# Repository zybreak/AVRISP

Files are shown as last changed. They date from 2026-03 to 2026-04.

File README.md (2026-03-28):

AVR ISP Shield for Arduino
===========================
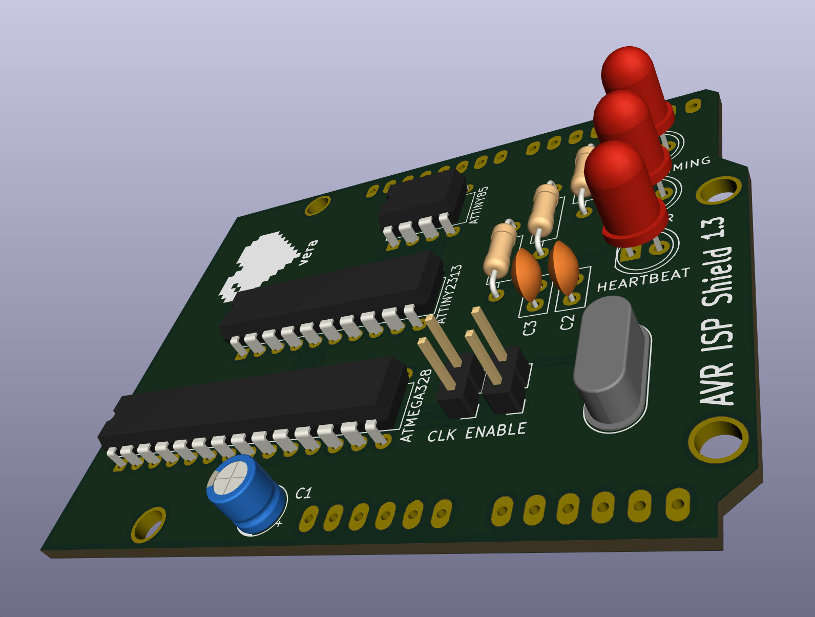
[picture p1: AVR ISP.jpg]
AVR ISP Shield of Arduino


This is an AVR ISP Shield for Arduino

Repository Contents
-------------------
* **/Hardware** - Kicad PCB .pro .sch and .brb files and PDF of Schematic
* **/Software** - Arduino Sketch for Using the Board

Version History
---------------
* V0.1 Functions well for the ATTiny85 but seem to be having problems with the ATMega328 - working on it!
* V1.0 Fully working - has a rearrange from previous versions which avoids grounding on the USB connector on an Uno.
* V1.3 Board update
   - Updated the LED pins to match the ones used in the arduino as isp sketch.
   - Added reset capacitor to prevent the arduino from resetting before programming.
   - Added support for an external clock.

License Information
-------------------
The hardware is released under [Creative Commons Share-alike 3.0](http://creativecommons.org/licenses/by-sa/3.0/).  
All other code is open source so please feel free to do anything you want with it; you buy me a beer if you use this and we meet someday ([Beerware license](http://en.wikipedia.org/wiki/Beerware)).
Also this boiler plate is yoinked from Sparkfun with thanks.

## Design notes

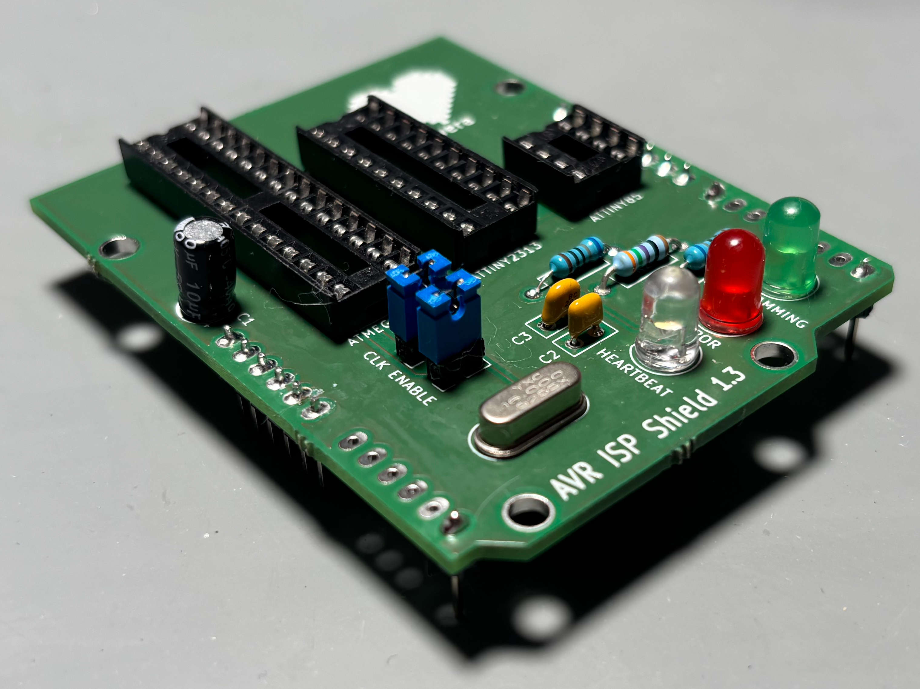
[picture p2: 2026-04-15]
AVR ISP Built.jpg

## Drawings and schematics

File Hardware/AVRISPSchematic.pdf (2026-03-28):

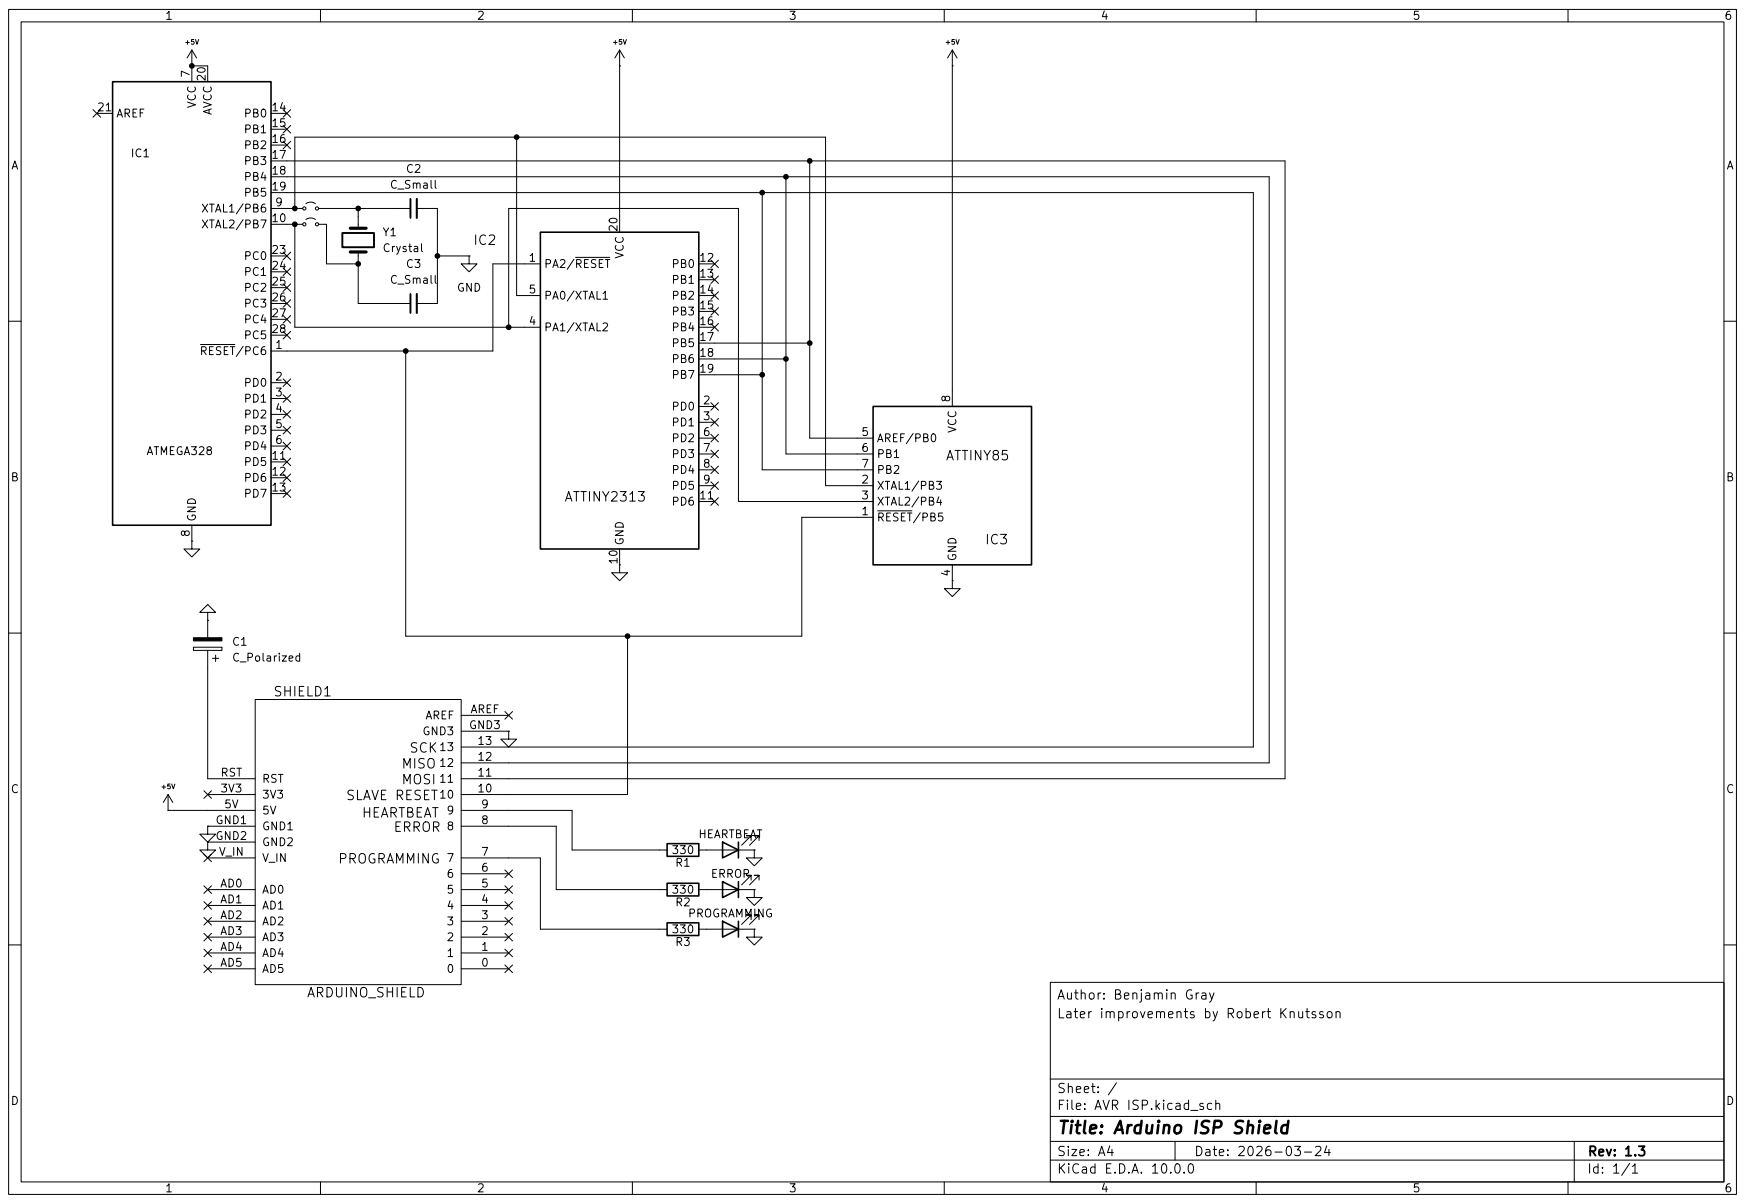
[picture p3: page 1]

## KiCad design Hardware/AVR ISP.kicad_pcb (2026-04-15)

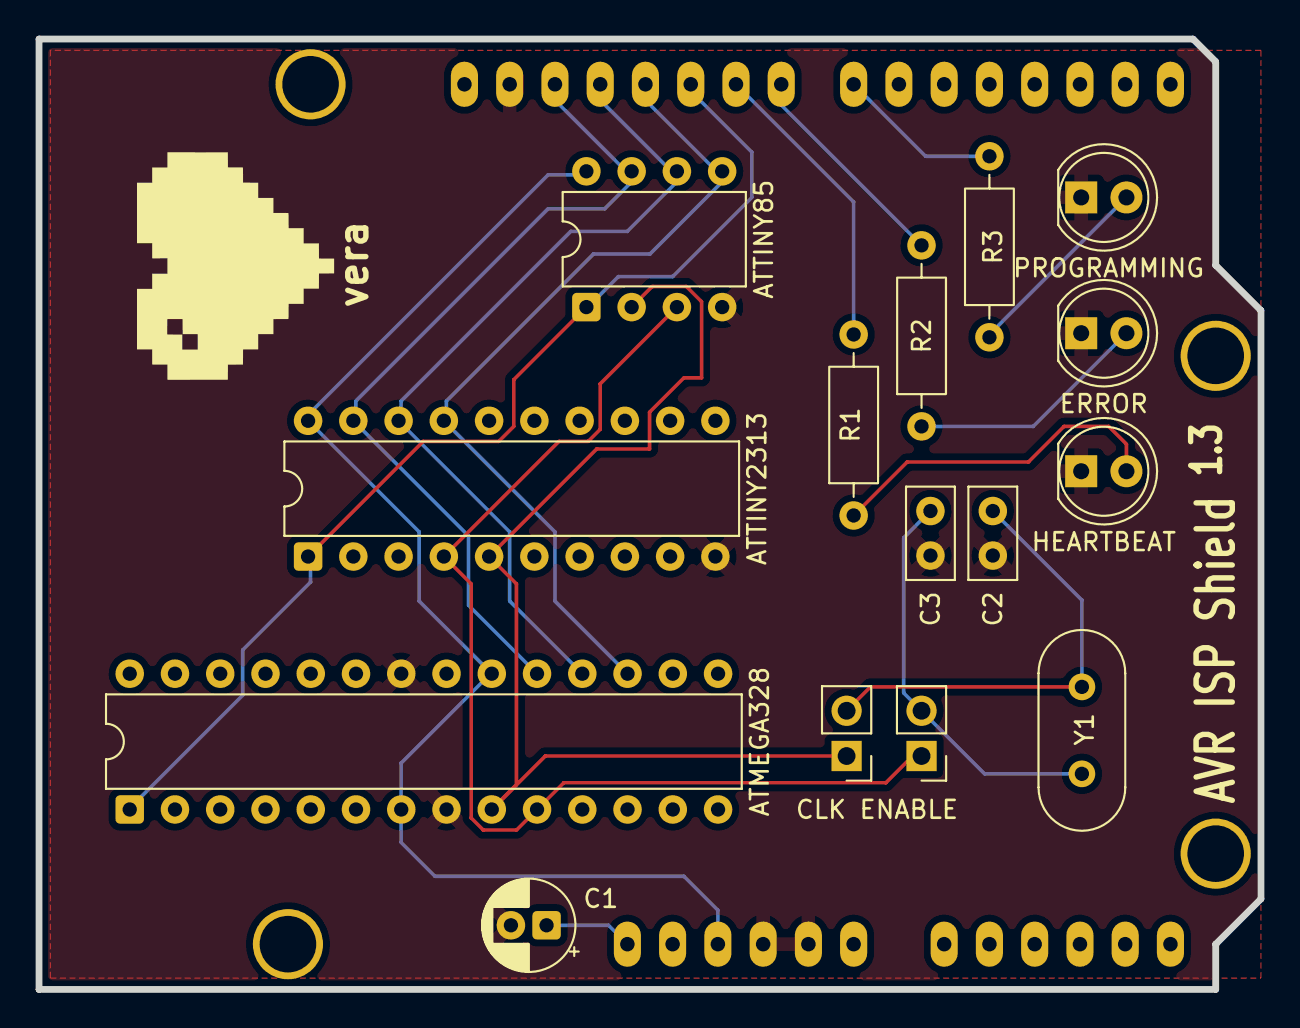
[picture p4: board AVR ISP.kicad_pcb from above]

Board: 2 copper layers, 68.6 x 53.3 mm, 16 parts (0 on the bottom side), 17 nets.

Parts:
C1: C_Polarized; CP_Radial_D5.0mm_P2.00mm
C2, C3: C_Small; C_Disc_D5.0mm_W2.5mm_P2.50mm
CLK ENABLE: PinHeader_1x02_P2.54mm_Vertical
D1: HEARTBEAT; LED_D5.0mm
D2: ERROR; LED_D5.0mm
D3: PROGRAMMING; LED_D5.0mm
IC1: ATMEGA328; DIP-28_W7.62mm
IC2: ATTINY2313; DIP-20_W7.62mm
IC3: ATTINY85; DIP-8_W7.62mm
JP2: PinHeader_1x02_P2.54mm_Vertical
R1, R2, R3: 330; R_Axial_DIN0207_L6.3mm_D2.5mm_P10.16mm_Horizontal
SHIELD1: ARDUINO_SHIELD
Y1: Crystal; Crystal_HC49-4H_Vertical

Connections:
+5V: IC1.7 (VCC), IC1.20 (AVCC), IC2.20 (VCC), IC3.8 (VCC), SHIELD1.5V
GND: C1.2, C2.2, C3.2, D1.1 (K), D2.1 (K), D3.1 (K), IC1.8 (GND), IC1.22 (GND), IC2.10 (GND), IC3.4 (GND), SHIELD1.GND1, SHIELD1.GND2, SHIELD1.GND3
unnamed: C1.1, SHIELD1.RST
unnamed: D1.2 (A), R1.1
unnamed: D2.2 (A), R2.1
unnamed: D3.2 (A), R3.1
unnamed: IC1.17 (PB3), IC2.17 (PB5), IC3.5 (AREF/PB0), SHIELD1.11
unnamed: IC1.18 (PB4), IC2.18 (PB6), IC3.6 (PB1), SHIELD1.12
unnamed: IC1.19 (PB5), IC2.19 (PB7), IC3.7 (PB2), SHIELD1.13
unnamed: CLK ENABLE.1 (A), IC1.9 (XTAL1/PB6), IC2.5 (PA0/XTAL1), IC3.2 (XTAL1/PB3)
unnamed: IC1.10 (XTAL2/PB7), IC2.4 (PA1/XTAL2), IC3.3 (XTAL2/PB4), JP2.1 (A)
unnamed: IC1.1 (~RESET/PC6), IC2.1 (PA2/~RESET), IC3.1 (~RESET/PB5), SHIELD1.10
unnamed: C2.1, CLK ENABLE.2 (B), Y1.2
unnamed: C3.1, JP2.2 (B), Y1.1
unnamed: R1.2, SHIELD1.9
unnamed: R2.2, SHIELD1.8
unnamed: R3.2, SHIELD1.7

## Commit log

2026-03-28 KiCad 10, reset cap, correct LED, opt ext clk
    Updated to KiCad 10 project files
    Added a capacitor between arduino reset and ground preventing a reset
    before programming.
    Updated LED pins
    Added support for an external clock source
    [AVR ISP.kicad_pcb, AVR ISP.kicad_sch]
2026-03-28 Updated 3d render and schematic pdf
2026-03-28 removed generated files, source of truth is in kicad files
2026-04-15 Updated PCB and images
    Updated PCB removing plating around the four sheild holes
    Added an image of the built PCB
    [AVR ISP.kicad_pcb, AVR ISP.kicad_sch]
